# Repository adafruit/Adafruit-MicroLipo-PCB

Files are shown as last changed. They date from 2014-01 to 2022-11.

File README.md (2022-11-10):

# Adafruit MicroLipo and MiniLipo Charging Boards/Backpacks

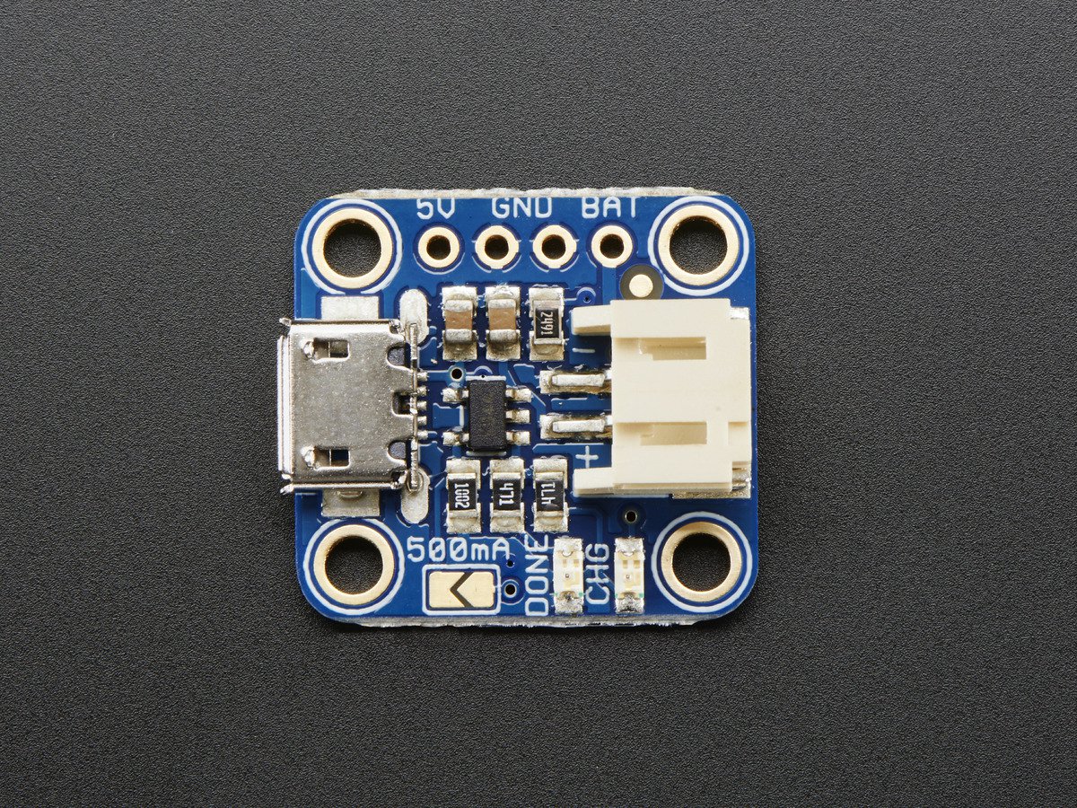
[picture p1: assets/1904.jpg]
&nbsp; 
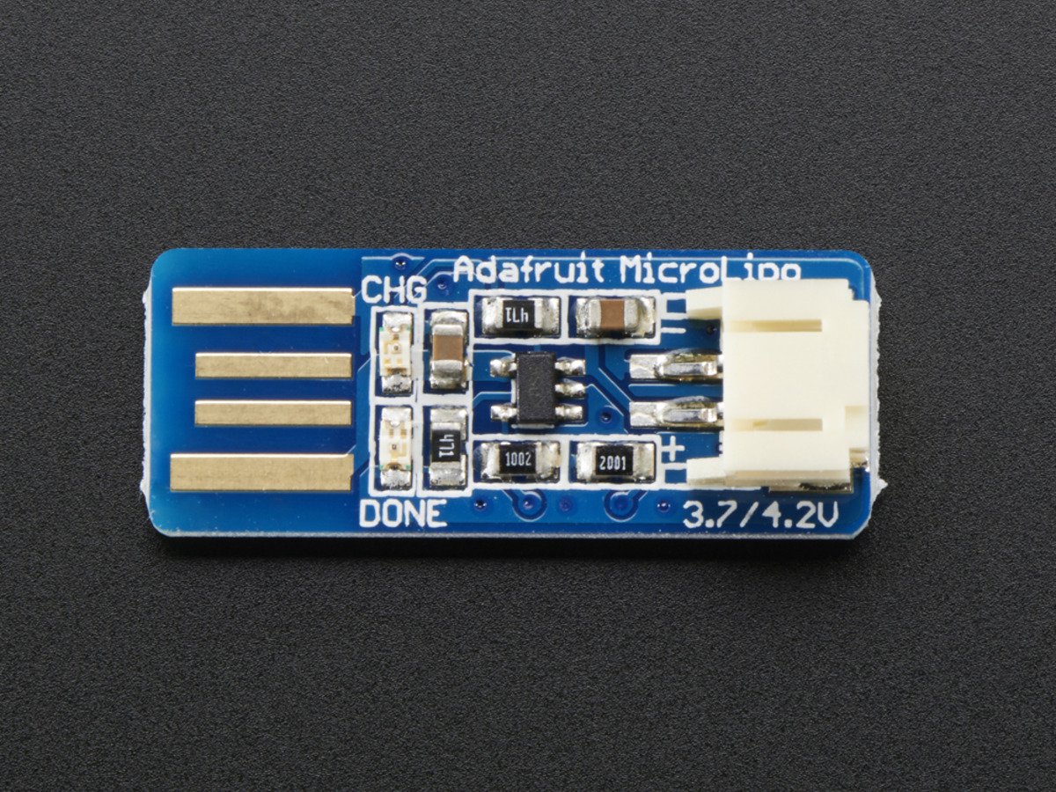
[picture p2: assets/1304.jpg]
<br />
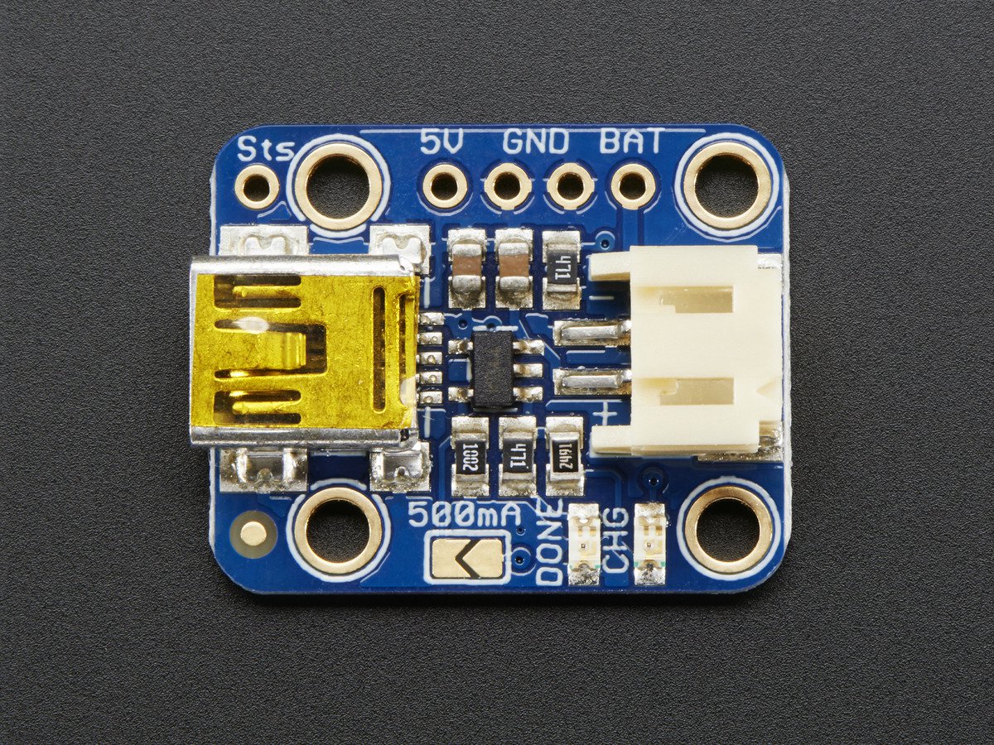
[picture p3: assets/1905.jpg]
&nbsp; 
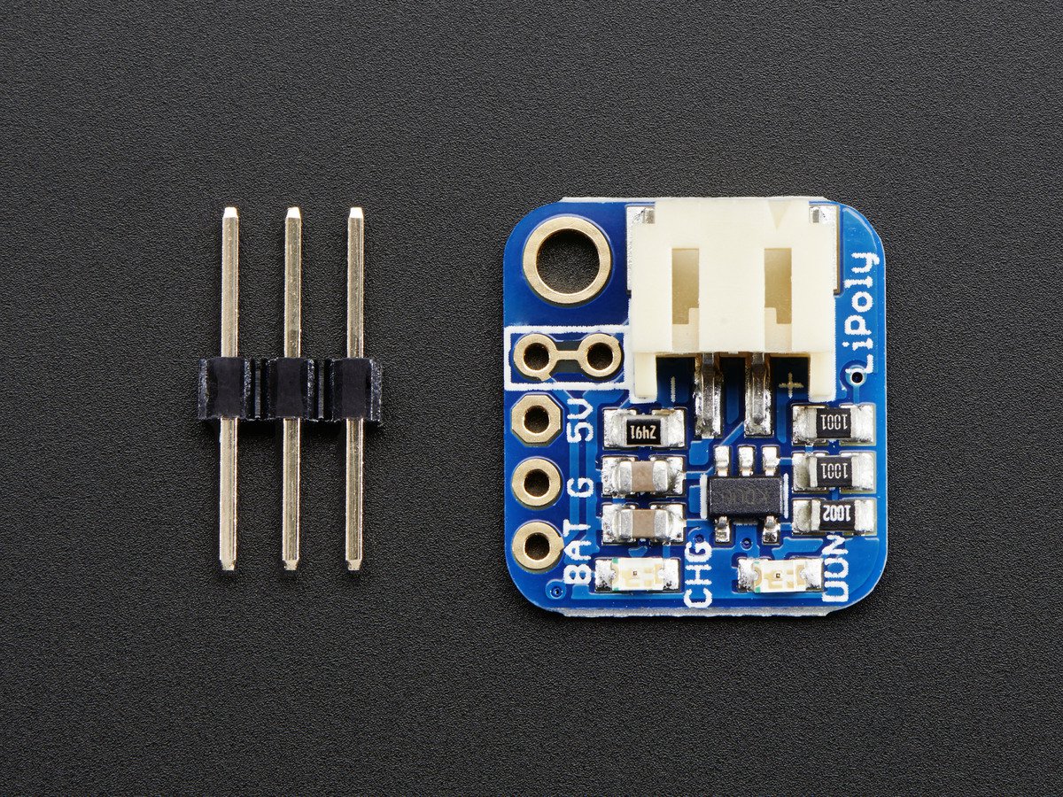
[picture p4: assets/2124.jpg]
<br />
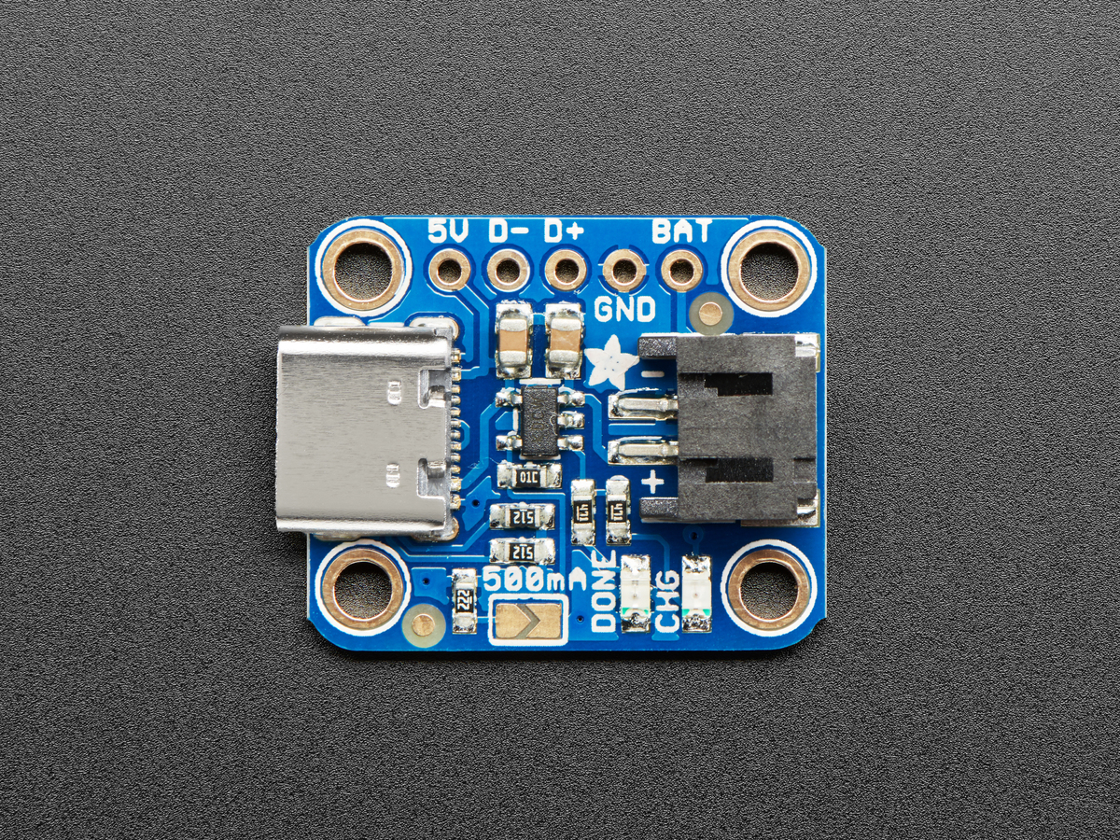
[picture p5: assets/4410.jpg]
&nbsp; 
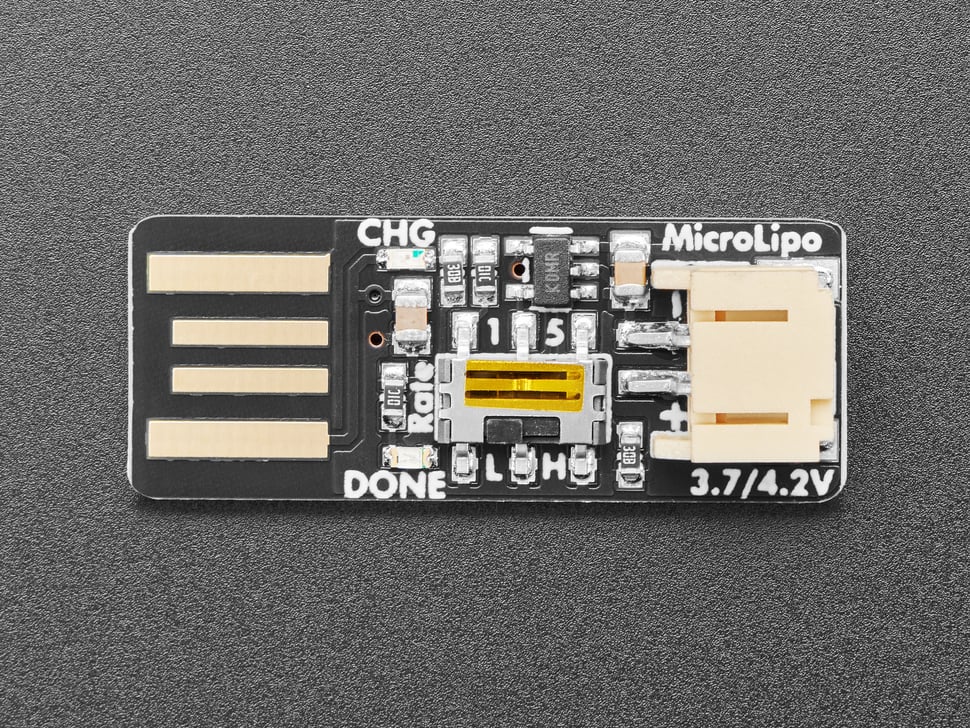
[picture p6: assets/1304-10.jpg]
<br />

Click to purchase from the Adafruit Shop:
- [Adafruit Micro-Lipo Charger for LiPo/LiIon Batt w/MicroUSB Jack - v1](https://www.adafruit.com/product/1904)
- [Adafruit Micro Lipo - USB LiIon/LiPoly charger - v1](https://www.adafruit.com/product/1304)
- [Adafruit Mini Lipo w/Mini-B USB Jack - USB LiIon/LiPoly charger - v1](https://www.adafruit.com/product/1905)
- [Adafruit LiIon/LiPoly Backpack Add-On for Pro Trinket/ItsyBitsy](https://www.adafruit.com/product/2124)
- [Adafruit Micro-Lipo Charger for LiPoly Batt with USB Type C Jack](https://www.adafruit.com/product/4410)
- [Adafruit Micro Lipo - USB LiIon/LiPoly charger - v2](https://www.adafruit.com/product/1304)

Oh so handy, this little lipo charger is so small and easy to use you can keep it on your desk or mount it easily into any project! Simply plug it via any MicroUSB cable into a USB port and a 3.7V/4.2V lithium polymer or lithium ion rechargeable battery into the JST plug on the other end. There are two LEDs - one red and one green. While charging, the red LED is lit. When the battery is fully charged and ready for use, the green LED turns on. Seriously, it could not get more easy.

These are the PCB files for the Adafruit Mini/MicroLipo battery chargers. The 
Format is EagleCAD schematic and board layout.

### License

Adafruit invests time and resources providing this open source design, please support Adafruit and open-source hardware by purchasing products from [Adafruit](https://www.adafruit.com)!

All text above must be included in any redistribution

Designed by Limor Fried/Ladyada for Adafruit Industries.
Creative Commons Attribution/Share-Alike, all text above must be included in any redistribution. 
See license.txt for additional information.

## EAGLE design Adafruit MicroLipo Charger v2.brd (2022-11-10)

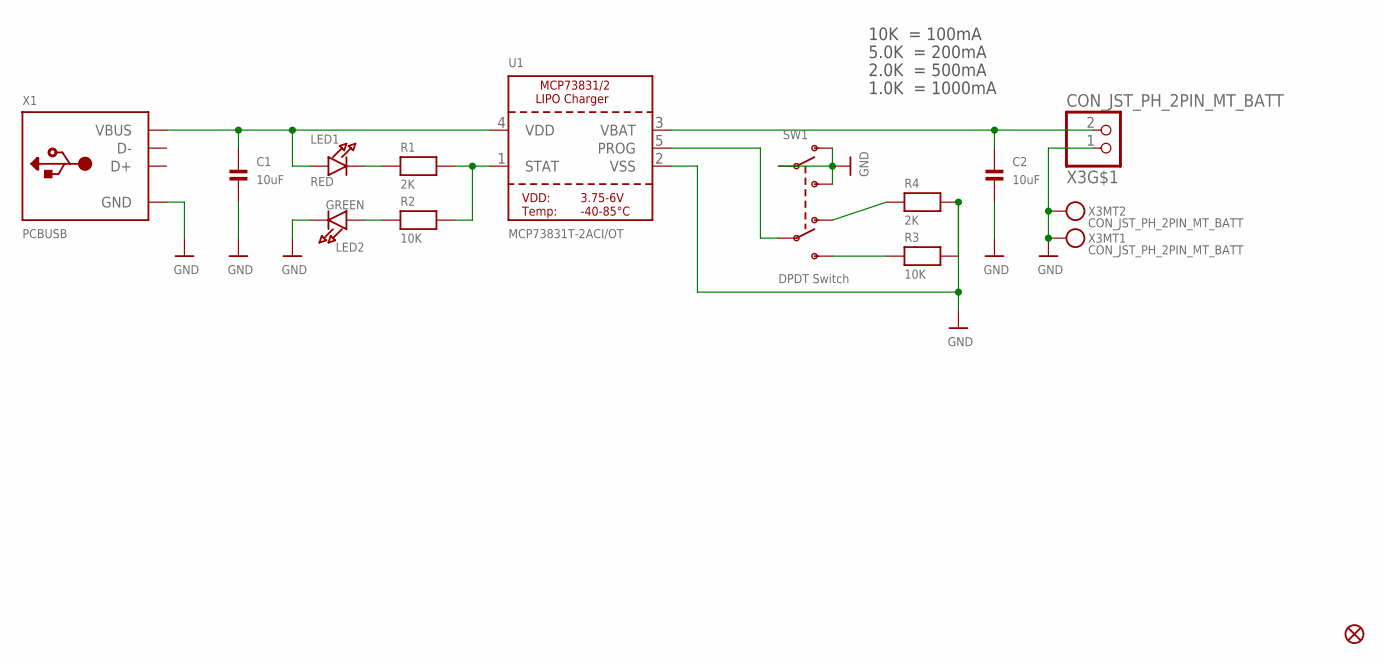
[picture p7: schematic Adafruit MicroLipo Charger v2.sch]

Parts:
C1, C2: 10uF; 0805-NO
FID1: FIDUCIAL_1MM
LED1: RED; CHIPLED_0603_NOOUTLINE
LED2: GREEN; CHIPLED_0603_NOOUTLINE
R1, R4: 2K; 0603-NO
R2, R3: 10K; 0603-NO
SW1: DPDT Switch; EG1390
U1: MCP73831T-2ACI/OT; SOT23-5
X1: PCBUSB; USBA_PCB
X3: CON_JST_PH_2PIN_MT_BATT; JSTPH2_BATT

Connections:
GND: C1.2, C2.2, LED2.C, R3.2, R4.2, SW1.O1, SW1.P1, SW1.S1, U1.2 (VSS), X1.GND, X3.1, X3.NC1, X3.NC2
unnamed: LED1.C, R1.1
unnamed: R1.2, R2.2, U1.1 (STAT)
unnamed: R3.1, SW1.S2
unnamed: R4.1, SW1.O2
unnamed: SW1.P2, U1.5 (PROG)
unnamed: LED2.A, R2.1
VBAT: C2.1, U1.3 (VBAT), X3.2
VDD: C1.1, LED1.A, U1.4 (VDD), X1.VCC (VBUS)

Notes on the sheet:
10K = 100mA
5.0K = 200mA
2.0K = 500mA
1.0K = 1000mA

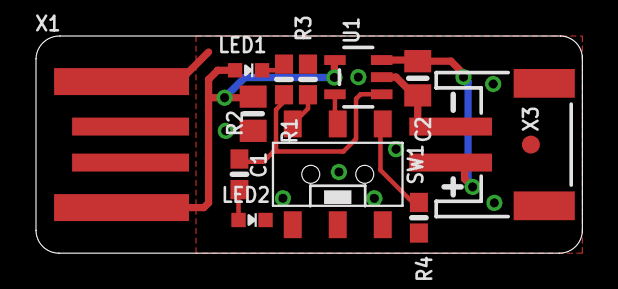
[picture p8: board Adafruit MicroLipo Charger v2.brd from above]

Board: 2 copper layers, 30.4 x 12.1 mm, 27 parts (5 on the bottom side), 9 nets.

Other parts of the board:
PLABEL0: PLABEL0
PLABEL1: PLABEL1
PLABEL2: PLABEL2
PLABEL3: PLABEL3
PLABEL4: PLABEL4
PLABEL5: PLABEL5
PLABEL6: PLABEL6
PLABEL7: PLABEL7
PLABEL8: PLABEL8
PLABEL9: PLABEL9
PLABEL10: PLABEL10
PLABEL11: PLABEL11
U$8: ADAFRUIT_TEXT_20MM
U$9: PCBFEAT-REV-040

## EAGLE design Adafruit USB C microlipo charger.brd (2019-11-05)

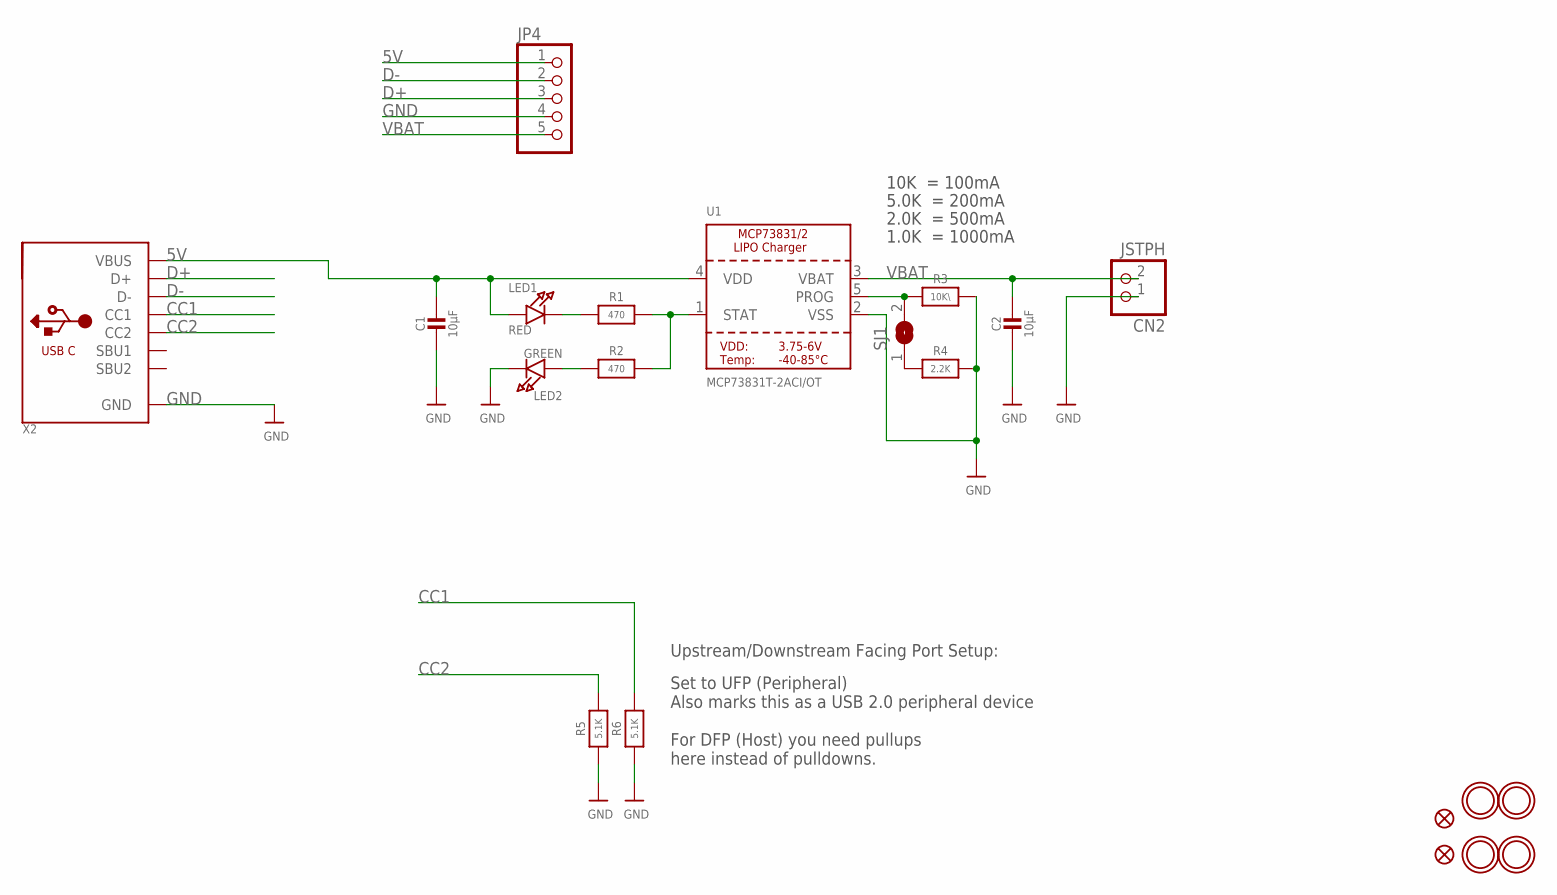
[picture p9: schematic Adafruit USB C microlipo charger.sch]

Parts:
C1, C2: 10µF; 0805-NO@1
CN2: JSTPH; JSTPH2
FID1, FID2: FIDUCIAL""; FIDUCIAL_1MM
JP4: HEADER-1X570MIL; 1X05_ROUND_70
LED1: RED; CHIPLED_0805_NOOUTLINE
LED2: GREEN; CHIPLED_0805_NOOUTLINE
R1, R2: 470; 0603-NO
R3: 10K\; 0603-NO
R4: 2.2K; 0603-NO
R5, R6: 5.1K; 0603-NO
SJ1: SOLDERJUMPER; SOLDERJUMPER_ARROW_NOPASTE
U1: MCP73831T-2ACI/OT; SOT23-5
U$9, U$10, U$11, U$12: MOUNTINGHOLE2.5; MOUNTINGHOLE_2.5_PLATED
X2: USB_C; USB_C_CUSB31-CFM2AX-01-X

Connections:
5V: C1.1, JP4.1, LED1.A, U1.4 (VDD), X2.A4B9 (VBUS), X2.B4A9 (VBUS)
CC1: R6.2, X2.A5 (CC1)
CC2: R5.2, X2.B5 (CC2)
D+: JP4.3, X2.A6 (D+), X2.B6 (D+)
D-: JP4.2, X2.A7 (D-), X2.B7 (D-)
GND: C1.2, C2.2, CN2.1, JP4.4, LED2.C, R3.2, R4.2, R5.1, R6.1, U1.2 (VSS), X2.A1B12 (GND), X2.B1A12 (GND)
unnamed: LED1.C, R1.1
unnamed: R1.2, R2.2, U1.1 (STAT)
unnamed: R4.1, SJ1.1
unnamed: R3.1, SJ1.2, U1.5 (PROG)
unnamed: LED2.A, R2.1
VBAT: C2.1, CN2.2, JP4.5, U1.3 (VBAT)

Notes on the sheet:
10K = 100mA
5.0K = 200mA
2.0K = 500mA
1.0K = 1000mA
Set to UFP (Peripheral) Also marks this as a USB 2.0 peripheral device For DFP (Host) you need pullups here instead of pulldowns.
Upstream/Downstream Facing Port Setup:

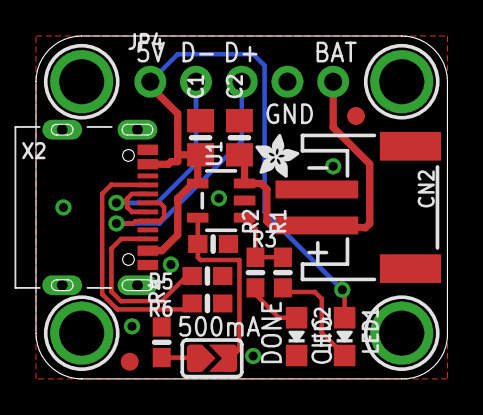
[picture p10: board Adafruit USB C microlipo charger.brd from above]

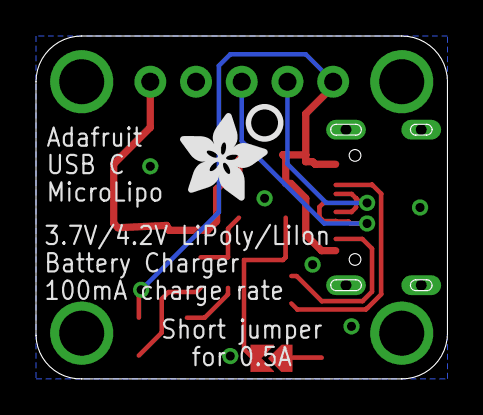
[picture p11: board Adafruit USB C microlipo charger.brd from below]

Board: 2 copper layers, 22.9 x 19.1 mm, 24 parts (2 on the bottom side), 12 nets.

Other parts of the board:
U$2: ADAFRUIT_2.5MM
U$13: ADAFRUIT_5MM
U$16: PCBFEAT-REV-040

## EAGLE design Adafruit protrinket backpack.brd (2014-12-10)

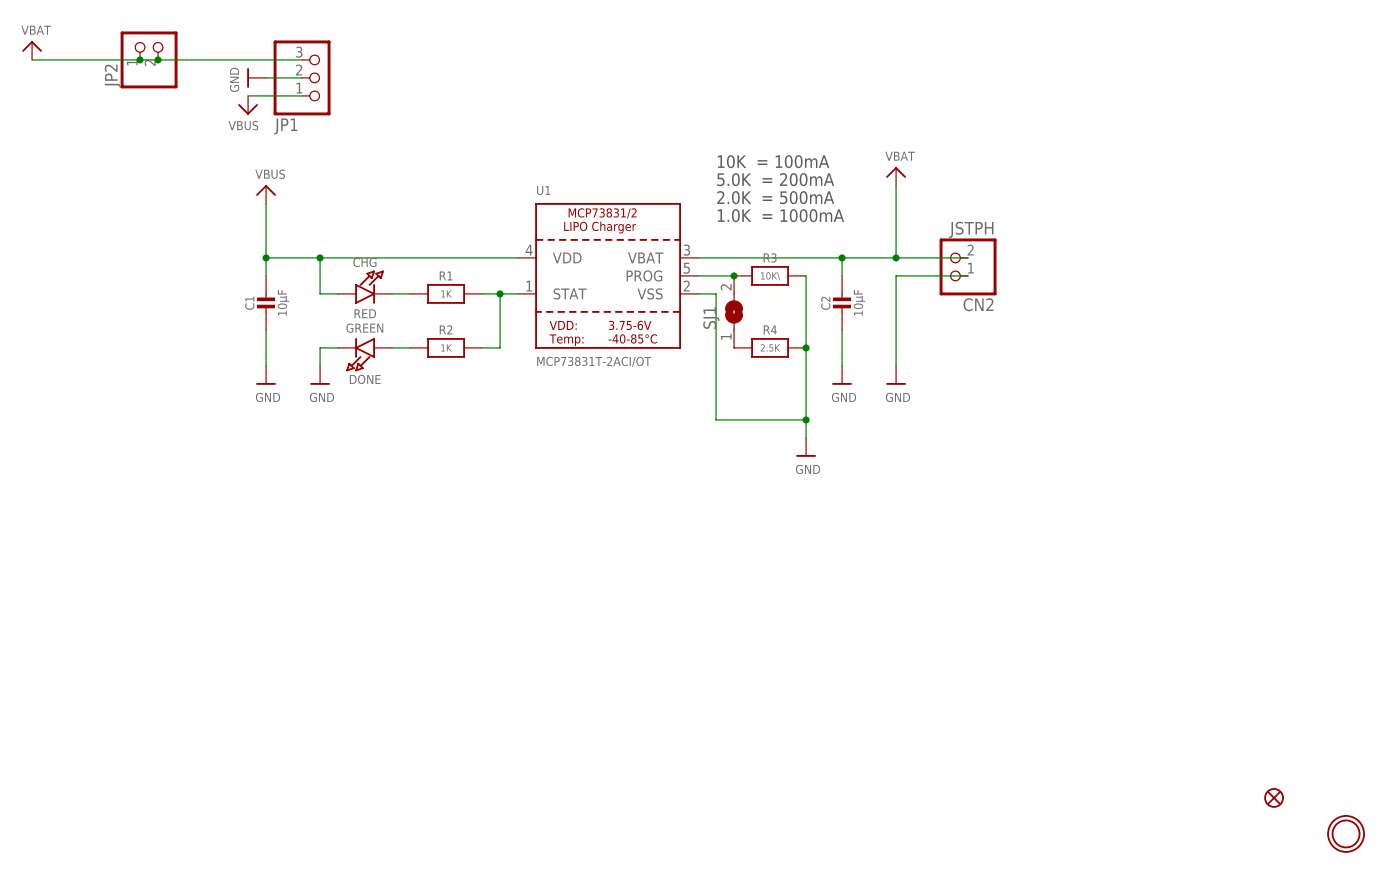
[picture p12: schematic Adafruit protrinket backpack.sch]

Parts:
C1, C2: 10µF; 0805-NO
CHG: RED; CHIPLED_0805_NOOUTLINE
CN2: JSTPH; JSTPH2
DONE: GREEN; CHIPLED_0805_NOOUTLINE
FID1: FIDUCIAL""; FIDUCIAL_1MM
JP1: HEADER-1X376MIL; 1X03_ROUND_76
JP2: HEADER-1X2ROUND; 1X02_ROUND
R1, R2: 1K; 0805-NO
R3: 10K\; _0805MP
R4: 2.5K; 0805-NO
SJ1: SOLDERJUMPER; SOLDERJUMPER_ARROW_NOPASTE
U1: MCP73831T-2ACI/OT; SOT23-5
U$10: MOUNTINGHOLE2.5; MOUNTINGHOLE_2.5_PLATED

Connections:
GND: C1.2, C2.2, CN2.1, DONE.C, JP1.2, R3.2, R4.2, U1.2 (VSS)
unnamed: CHG.C, R1.1
unnamed: R1.2, R2.2, U1.1 (STAT)
unnamed: R4.1, SJ1.1
unnamed: R3.1, SJ1.2, U1.5 (PROG)
unnamed: DONE.A, R2.1
VBAT: C2.1, CN2.2, JP1.3, JP2.1, JP2.2, U1.3 (VBAT)
VBUS: C1.1, CHG.A, JP1.1, U1.4 (VDD)

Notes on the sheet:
10K = 100mA
5.0K = 200mA
2.0K = 500mA
1.0K = 1000mA

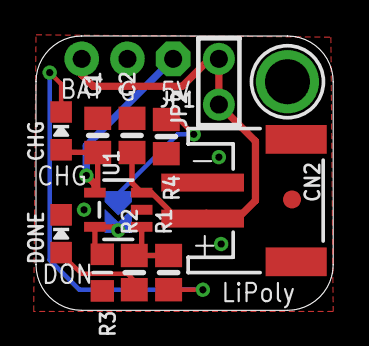
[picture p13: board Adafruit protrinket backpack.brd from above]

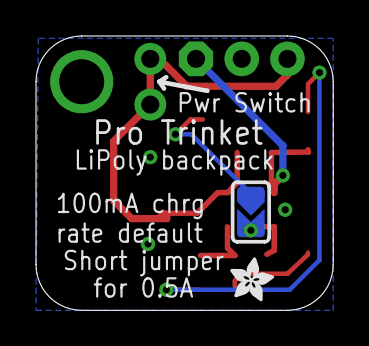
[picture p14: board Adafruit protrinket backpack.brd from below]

Board: 2 copper layers, 16.5 x 15.2 mm, 16 parts (2 on the bottom side), 8 nets.

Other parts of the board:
U$9: ADAFRUIT_2.5MM

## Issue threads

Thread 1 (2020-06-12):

STs pin

YangLuSE, 2020-06-12:
Hi, I'm trying to get status for charging. Could you please post a demo code or library for STs pin on board? Thanks! It's on the board 1905.

ladyada, 2020-06-12:
its a digital output. use ST demo code for digital pins

YangLuSE, 2020-06-15:
Could you please share the link? Cannot find any demo code for this board.

Closed 2020-06-12.

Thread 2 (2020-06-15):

Could you please tell me which library I can use?

YangLuSE, 2020-06-15:
its a digital output. use ST demo code for digital pins

_Originally posted by @ladyada in https://github.com/adafruit/Adafruit-MicroLipo-PCB/issues/1#issuecomment-643411471_

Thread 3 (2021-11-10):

Question: What is the partnumber of the type-c usb connector used?

dmsherazi, 2021-11-10:
May I know the part number or have a link to the datasheet of the usb-typec connector that is used in this board.

Is it the one from LCSC - Mfr no: 918-418K2023S40001 LCSC no: C167321

ladyada, 2021-11-10:
https://www.adafruit.com/product/4458

Closed 2021-11-10.

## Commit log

2014-07-22 new revs with usb!
    [Adafruit MicroUSB Lipo.brd, Adafruit MicroUSB Lipo.sch, Adafruit MiniLipo.brd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]
2014-12-10 added the pro trinket version
    [Adafruit protrinket backpack.brd, Adafruit protrinket backpack.sch]
2022-11-10 adding v2 microlipo
    [Adafruit MicroLipo Charger v2.brd, Adafruit MicroLipo Charger v2.sch]

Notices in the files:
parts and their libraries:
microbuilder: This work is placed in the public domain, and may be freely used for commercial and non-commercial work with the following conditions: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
